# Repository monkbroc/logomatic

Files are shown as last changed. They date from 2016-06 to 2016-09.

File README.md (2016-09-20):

# Logomatic

A gorgeous internet-connected animated logo.

Animated logo (https://www.youtube.com/watch?v=NtJe1kALyLk)

### [Read a writeup about the project](writeup.md) (work in progress)

## Parts

Hardware: PCB, bill of materials

Firmware: software to read animated GIFs and control the LEDs.

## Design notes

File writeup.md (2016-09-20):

# Logomatic

## Make a logo come alive with full color animations

TODO: Better intro

This project combines many maker skills to create a logo sign using laser cut acrylic, a custom printed PCB to drive the LED string and software to play the animations and receive commands through the internet.

# Initial design

TODO: insert napkin drawing

The idea was to build the logo using laser cut acrylic in 3 layers and have LEDs shine through the logo.

The base layer would be opaque white with a hole in the shape of the logo and space for the name. It would also have holes for standoffs, fancy machined aluminium cylinders used to mount the sign to the wall.

The top layer would be frosted acrylic in the shape of the logo, but slightly larger than the hole. The top layer would also have the name in black to make it pop.

The bottom layer would be opaque white with a single strip of Neopixel LEDs cut and glued to it. The LEDs would shine through the top frosted layer.

The layers would be fastened together in some way that would be determined later.

I knew wiring the LEDs would be a pain, but it could be done with enough patience.

Since this was a Particle logo sign I wanted to show off the Particle

The software should be able to play GIF animations from an SD card and also perform so hard-coded animations like breathing a color like the Particle devices do when connected to the internet.

# Drawing template

Lay out the sign that you want to make in Inkscape or Illustrator. Add
the logo and text and the 4 standoffs in the corners. Use little
rectangles the same size as the LEDs to make a nice pattern.

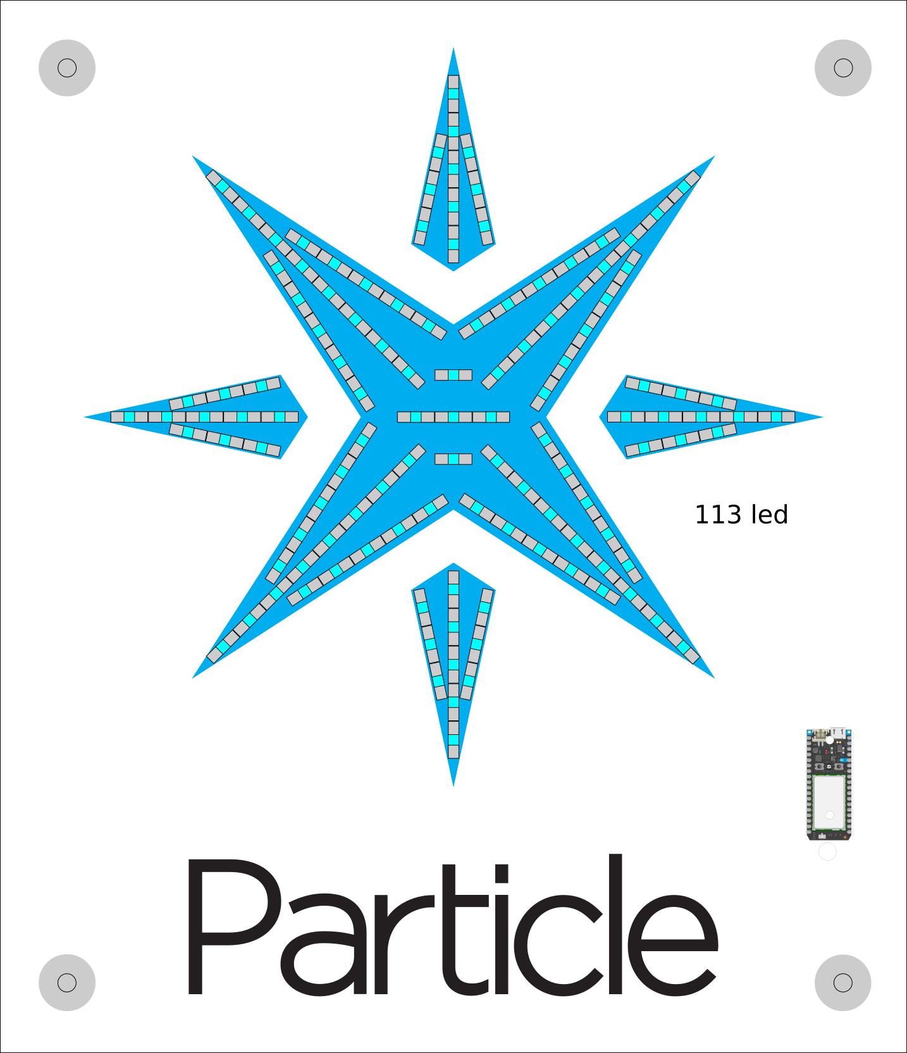
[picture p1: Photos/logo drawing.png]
Drawing template


## Laser cutting

When you are happy with the layout, copy the drawing and turn it into vectors that will be used to drive the laser cutter.

I needed 4 vectors. You can see them in `Mechanical/laser cutter vectors.svg`

First the letters are just cut in a piece of black acrylic.

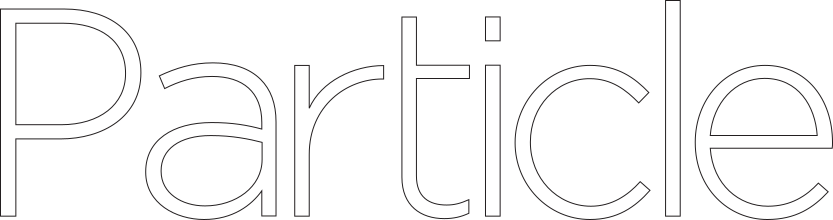
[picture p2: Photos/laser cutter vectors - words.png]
Laser cutter words


Second the logo top layer is just cut in a piece of transparent acrylic. I rotated the points to save material.

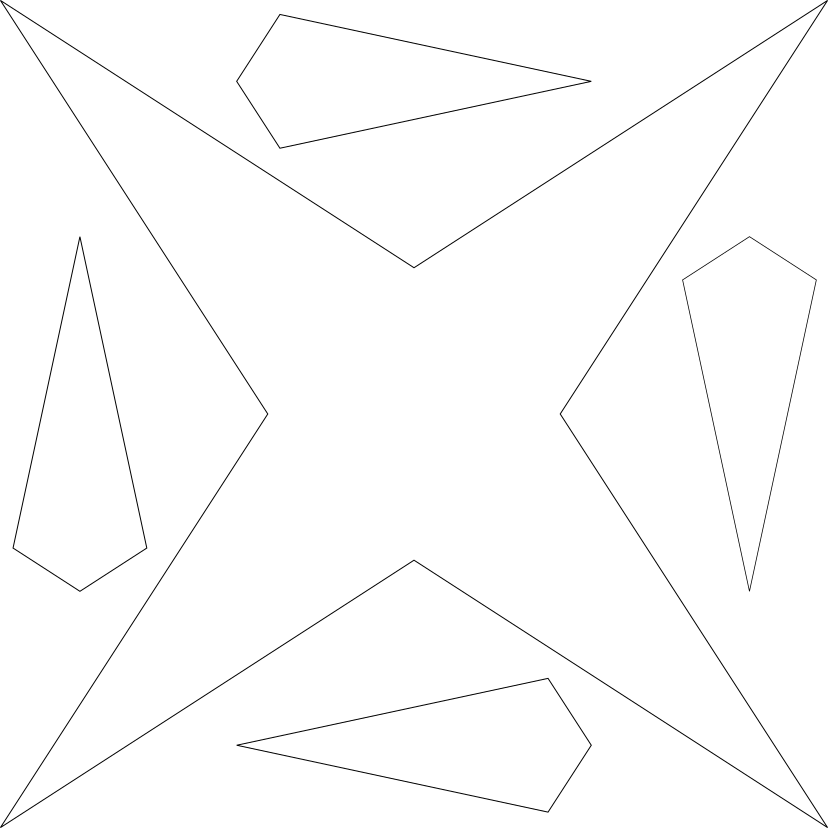
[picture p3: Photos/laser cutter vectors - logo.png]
Laser cutter logo


Third is the base plate cut in a piece of white acrylic. The logo is hole is slighly smaller than the logo top layer. I did this in Inkscape by using Path -> Dynamic offset on the logo and shrinking the logo outline a bit. Using the same technique I made a shrunk down copy of the letters. Instead of cutting those I just etched them to know where to glue the black letters on the base plate.

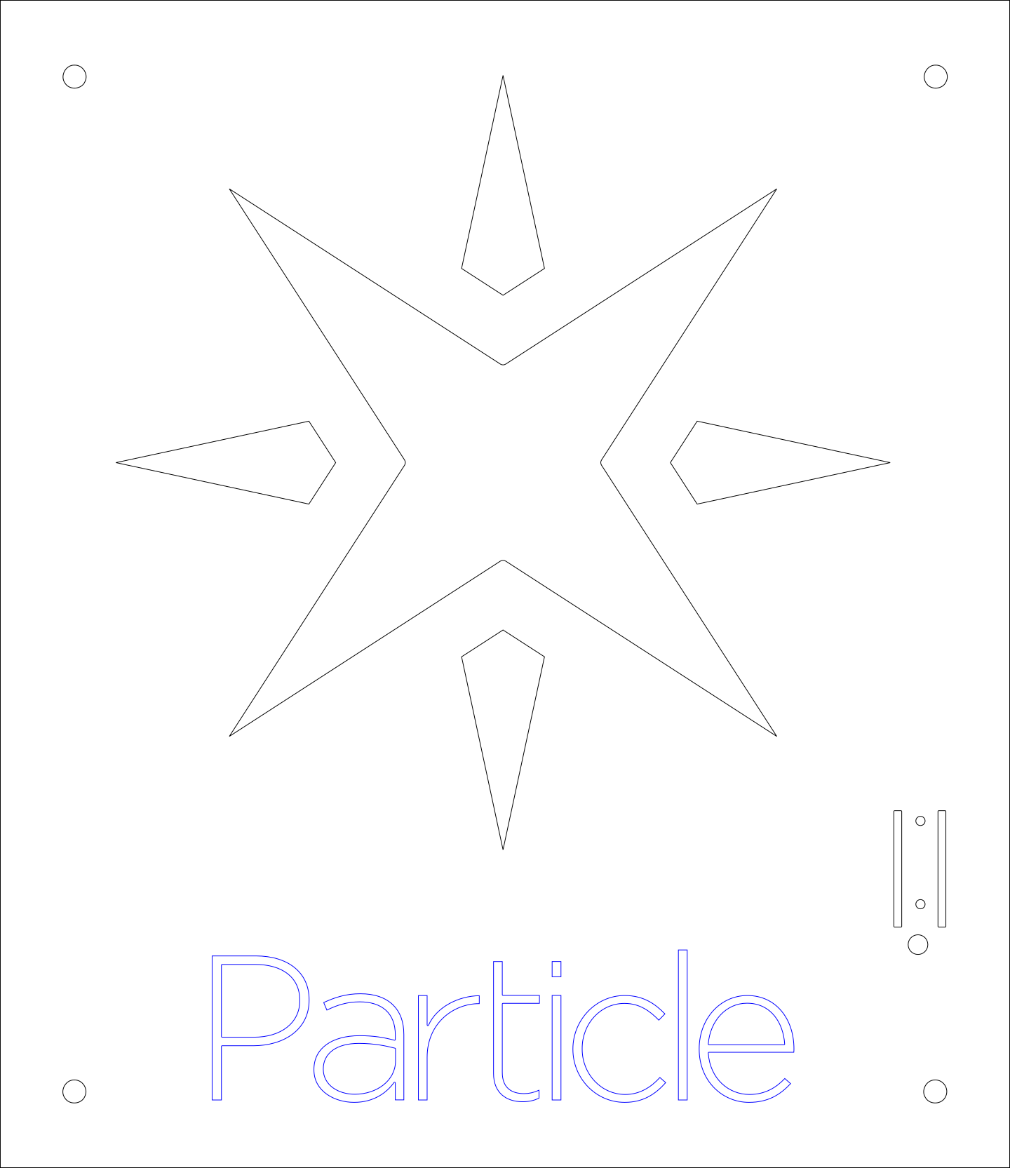
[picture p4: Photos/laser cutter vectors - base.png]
Laser cutter base


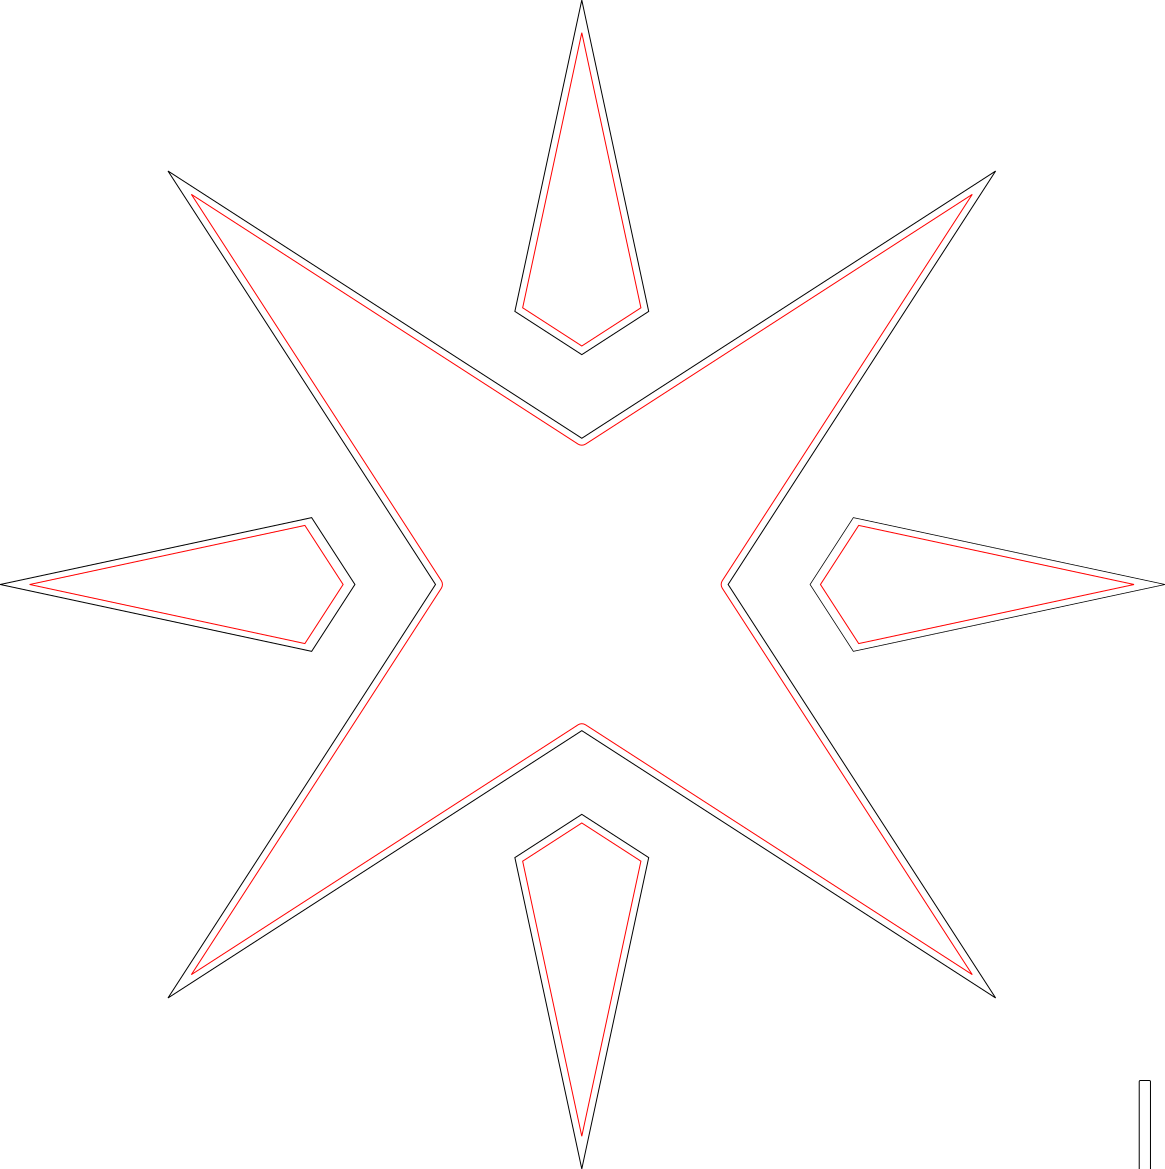
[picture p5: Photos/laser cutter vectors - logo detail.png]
Laser cutter logo details


Finally the back layer holding the LEDs is cut in a piece of white acrylic. The cut outline is made by using Dynamic offset and enlarging the logo. The logo hole and ideal placement of the LEDs are etched to ease assembly later.

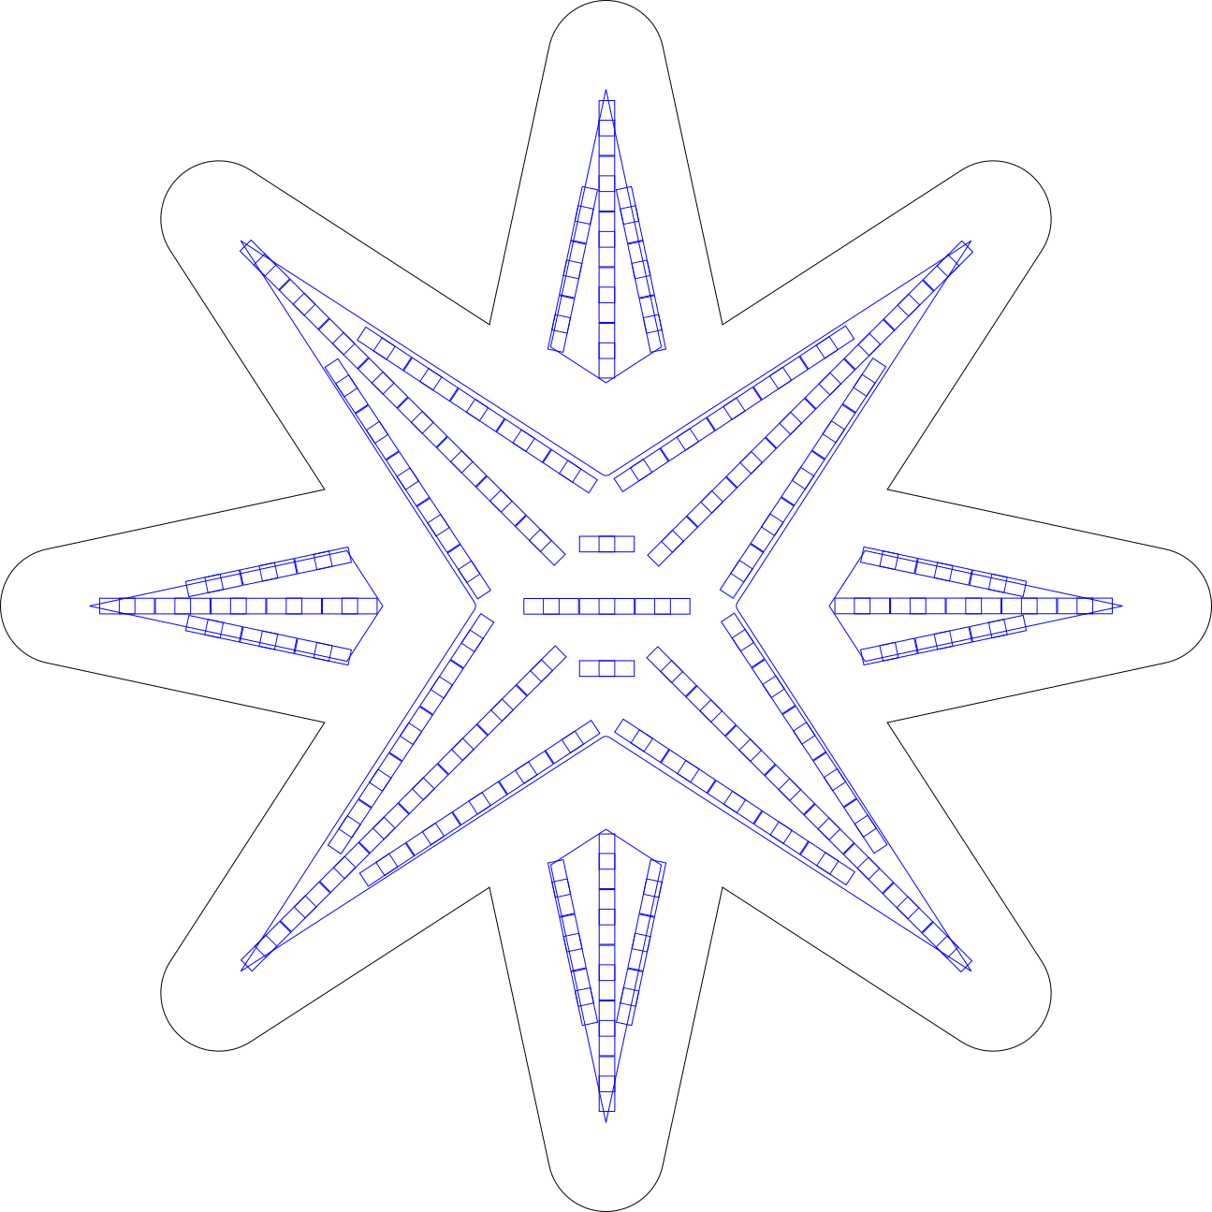
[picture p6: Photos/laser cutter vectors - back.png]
Laser cutter back


Take the files to your local maker space and go cut some plastic!

Here's the result of cutting the base plate.

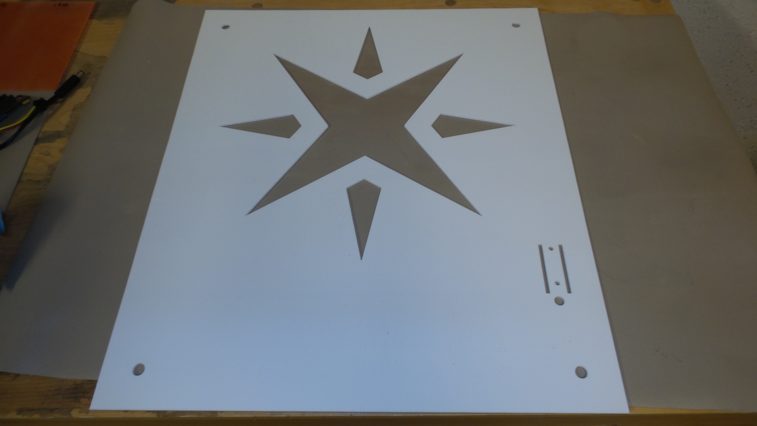
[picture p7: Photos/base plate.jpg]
Base plate


## Assembly

The owner of the plastics shop where I bought my acrylic in Ann Arbor told me that Weld On 4 was the best product for cleanly glueing acryclic. He sold me a small bottle with a seringe that has a goose neck. He mentioned not to use a seringe with a steel needle otherwise I'd need as many needles as drops of glue!

The trick to use Weld On 4 is to place the pieces together, inject a small amount at the seam and wait 3 seconds. That's all it takes to make a strong bond! Weld On 4 melts the acrylic so the 2 pieces become one.

I started by glueing the black letters on the base place using the etched letters on the base plate as a guide.

Before glueing the top logo I sanded the transparent acrylic with an orbital sander and 80 grit sandpaper. I used very little pressure not to create deep swirls on the surface. The result is a nicely frosted piece of acrylic.

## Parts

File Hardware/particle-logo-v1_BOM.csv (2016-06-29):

Qty-1 | Part References | Value | Package | Mfg Part Num | Mfg Name | VID | Vendor Part Num | Description | XREF
1 | C3 | 0.1uF | C0603 | CC0603JRX7R7BB104 | Yageo | DK | 311-1776-1-ND | CAP CER 0.1UF 16V X7R 0603 | REF12
1 | C2 | 1.0UF | 0603-CAP | 0603YD105KAT2A | AVX | DK | 478-1249-1-ND | 1µF ±10% 16V X5R Ceramic Capacitor -55°C ~ 85°C Surface Mount | MLCC 0603 (1608 Metric) | REF52
2 | R1, R3 | 10k | R0603 | ERJ-3EKF1002V | Panasonic | DK | P10.0KHCT-ND | RES SMD 10K OHM 1% 1/10W 0603 | REF54
1 | C4 | 100UF | EIA7343 | TAJD107K020RNJ | AVX | DK | 478-1724-1-ND | CAP TANT 100UF 20V 10% 2917 | REF53
1 | R2 | 220 | R0603 | ERJ-3GEYJ221V | Panasonic | DK | P220GCT-ND | RES SMD 220 OHM 5% 1/10W 0603 | REF55
1 | C1 | 1000uF | CPOL-8MMX20MM-FLAT-MIR | EEU-FR1C102L | Panasonic Electronic Components | DK | P14397-ND | CAP ALUM 1000UF 20% 16V RADIAL | REF51
1 | U2 | APDS-9960 | APDS-9960 | APDS-9960 | Broadcom | AR | apds-9960/broadcom-limited | Light to Digital Ambient Light Sensor 8-Pin | REF57
2 | HEADER1, HEADER2 | BOM-ENTRY | * | PPTC181LFBN-RC | Sullins Connector Solutions | DK | S7016-ND | CONN HEADER FEMALE 18POS.1"" TIN | REF23
1 | R4(DNP), U3 | ELECTRON_WITH_EXTERNAL_HEADERS_NT | ELECTRON_EXTERNAL_NT | ***PART# '*' NOT FOUND*** | * | * | * | * | *
1 | U4 | NL17SZ125SOT553 | SOT-553 | NL17SZ125DTT1G | ON Semiconductor | DK | NL17SZ125DTT1GOSCT-ND | IC BUFFER NONINV 3ST 5TSOP | REF56
2 | JP2, JP1 | PRT-08235 | SCREWTERMINAL-3.5MM-3 | ***PART# '*' NOT FOUND*** | * | * | * | * | *
1 | U1 | USD-SOCKETMOLEX-CORRECT | MICRO-SD-MOLEX-CORRECT | 1040310811 | Molex | DK | WM6357CT-ND | CONN MICRO SD CARD PUSH-PULL R/A | REF24

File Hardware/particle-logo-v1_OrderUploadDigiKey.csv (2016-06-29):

Digi-Key Part No. | Manufacturer Name | Mfr Part No. | Customer Reference | Qty1
* | * | * | JP1/JP2/R4/U3 | 3 | *** PART# '*' NOT FOUND : JP1/JP2/R4/U3
478-1249-1-ND | AVX | 0603YD105KAT2A | C2 | 1
WM6357CT-ND | Molex | 1040310811 | U1 | 1
311-1776-1-ND | Yageo | CC0603JRX7R7BB104 | C3 | 1
P14397-ND | Panasonic Electronic Components | EEU-FR1C102L | C1 | 1
P10.0KHCT-ND | Panasonic | ERJ-3EKF1002V | R1/R3 | 2
P220GCT-ND | Panasonic | ERJ-3GEYJ221V | R2 | 1
NL17SZ125DTT1GOSCT-ND | ON Semiconductor | NL17SZ125DTT1G | U4 | 1
S7016-ND | Sullins Connector Solutions | PPTC181LFBN-RC | HEADER1/HEADER2 | 2
478-1724-1-ND | AVX | TAJD107K020RNJ | C4 | 1

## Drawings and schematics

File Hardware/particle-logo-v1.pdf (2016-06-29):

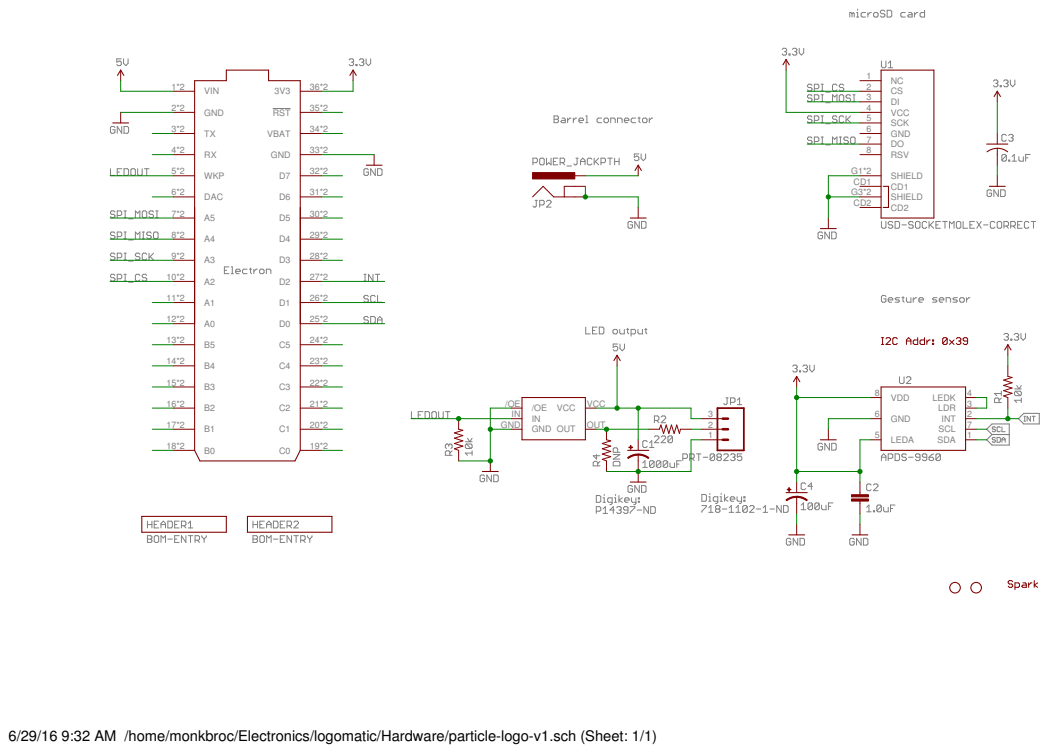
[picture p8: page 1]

6/29/16 9:32 AM /home/monkbroc/Electronics/logomatic/Hardware/particle-logo-v1.sch (Sheet: 1/1)

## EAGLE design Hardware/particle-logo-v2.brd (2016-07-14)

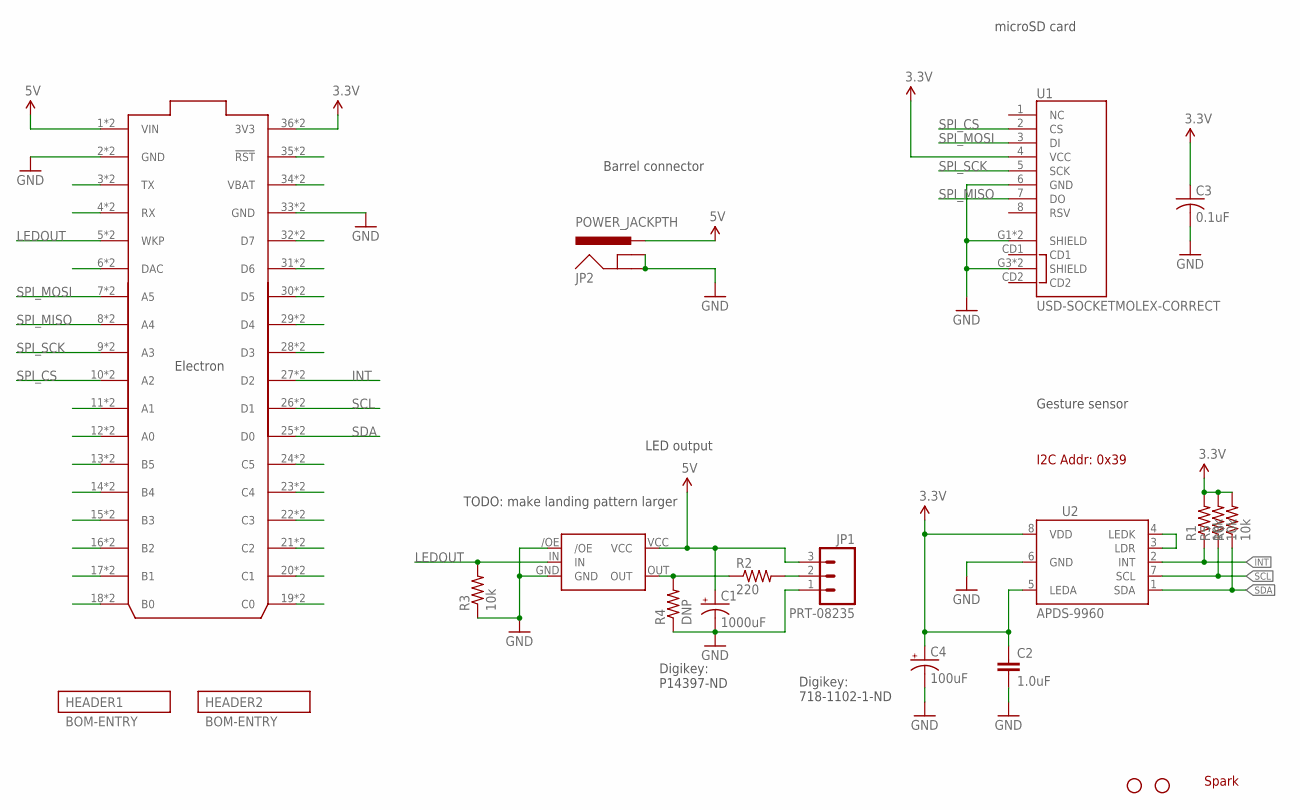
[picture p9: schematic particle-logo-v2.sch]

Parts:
C1: 1000uF; CPOL-8MMX20MM-FLAT-MIR; PARTNO EEU-FR1C102L
C2: 1.0uF; 0603-CAP; PARTNO 0603YD105KAT2A
C3: 0.1uF; C0603; PARTNO CC0603JRX7R7BB104
C4: 100uF; EIA7343; PARTNO TAJD107K020RNJ
JP1: PRT-08235; SCREWTERMINAL-3.5MM-3
JP2: POWER_JACKPTH; POWER_JACK_PTH
R1, R3, R5, R6: 10k; R0603; PARTNO ERJ-3EKF1002V
R2: 220; R0603; PARTNO ERJ-3GEYJ221V
R4: DNP; R0603
STANDOFF1, STANDOFF2: STAND-OFF
U1: USD-SOCKETMOLEX-CORRECT; MICRO-SD-MOLEX-CORRECT; PARTNO 1040310811
U2: APDS-9960; PARTNO APDS-9960
U3: ELECTRON_WITH_EXTERNAL_HEADERS_NT; ELECTRON_EXTERNAL_NT
U4: NL17SZ125SOT553; SOT-553; PARTNO NL17SZ125DTT1G
U$1: SPARK_LOGO2

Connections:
3.3V: C2.1, C3.1, C4.A (+), R1.2, R5.2, R6.2, U1.4 (VCC), U2.5 (LEDA), U2.8 (VDD), U3.36 (3V3), U3.@36 (3V3)
5V: C1.2 (+), JP1.3, JP2.PWR, U3.1 (VIN), U3.@1 (VIN), U4.VCC
GND: C1.1 (-), C2.2, C3.2, C4.C (-), JP1.1, JP2.GND, JP2.GNDBREAK, R3.1, R4.1, U1.6 (GND), U1.G1 (SHIELD), U1.G2 (SHIELD), U1.G3 (SHIELD), U1.G4 (SHIELD), U2.6 (GND), U3.2 (GND), U3.33 (GND), U3.@2 (GND), U3.@33 (GND), U4./OE, U4.GND
INT: R1.1, U2.2 (INT), U3.27 (D2), U3.@27 (D2)
LEDOUT: R3.2, U3.5 (WKP), U3.@5 (WKP), U4.IN
unnamed: R2.1, R4.2, U4.OUT
unnamed: U2.3 (LDR), U2.4 (LEDK)
unnamed: JP1.2, R2.2
unnamed: U3.3 (TX), U3.@3 (TX)
unnamed: U3.4 (RX), U3.@4 (RX)
unnamed: U3.6 (DAC), U3.@6 (DAC)
unnamed: U3.11 (A1), U3.@11 (A1)
unnamed: U3.12 (A0), U3.@12 (A0)
unnamed: U3.13 (B5), U3.@13 (B5)
unnamed: U3.14 (B4), U3.@14 (B4)
unnamed: U3.15 (B3), U3.@15 (B3)
unnamed: U3.16 (B2), U3.@16 (B2)
unnamed: U3.17 (B1), U3.@17 (B1)
unnamed: U3.18 (B0), U3.@18 (B0)
unnamed: U3.19 (C0), U3.@19 (C0)
unnamed: U3.20 (C1), U3.@20 (C1)
unnamed: U3.21 (C2), U3.@21 (C2)
unnamed: U3.22 (C3), U3.@22 (C3)
unnamed: U3.23 (C4), U3.@23 (C4)
unnamed: U3.24 (C5), U3.@24 (C5)
unnamed: U3.28 (D3), U3.@28 (D3)
unnamed: U3.29 (D4), U3.@29 (D4)
unnamed: U3.30 (D5), U3.@30 (D5)
unnamed: U3.31 (D6), U3.@31 (D6)
unnamed: U3.32 (D7), U3.@32 (D7)
unnamed: U3.34 (VBAT), U3.@34 (VBAT)
unnamed: U3.35 (!RST), U3.@35 (!RST)
SCL: R5.1, U2.7 (SCL), U3.26 (D1), U3.@26 (D1)
SDA: R6.1, U2.1 (SDA), U3.25 (D0), U3.@25 (D0)
SPI_CS: U1.2 (CS), U3.10 (A2), U3.@10 (A2)
SPI_MISO: U1.7 (DO), U3.8 (A4), U3.@8 (A4)
SPI_MOSI: U1.3 (DI), U3.7 (A5), U3.@7 (A5)
SPI_SCK: U1.5 (SCK), U3.9 (A3), U3.@9 (A3)

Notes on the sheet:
I2C Addr: 0x39
Gesture sensor
microSD card
Barrel connector
LED output
Digikey: 718-1102-1-ND
Digikey: P14397-ND
TODO: make landing pattern larger

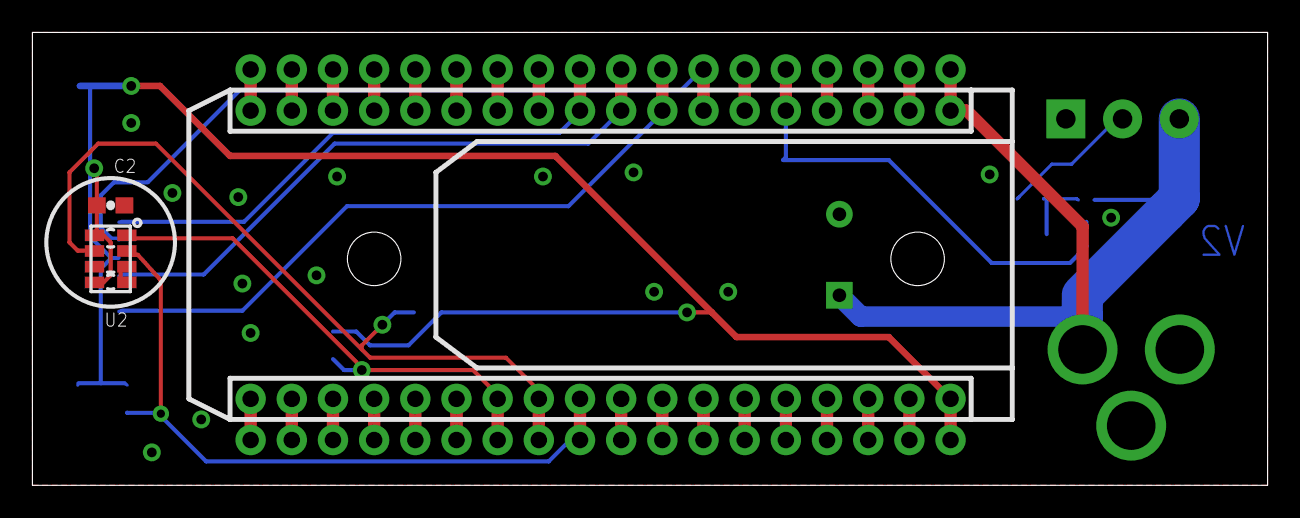
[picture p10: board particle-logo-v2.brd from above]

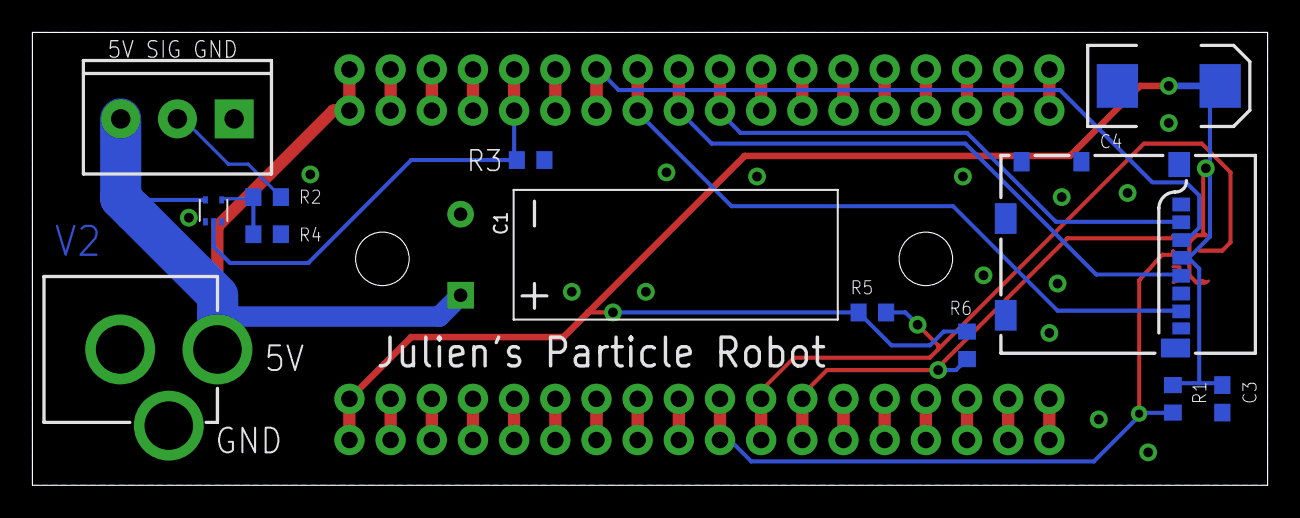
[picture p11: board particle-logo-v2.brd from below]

Board: 2 copper layers, 76.2 x 27.9 mm, 19 parts (16 on the bottom side), 38 nets.

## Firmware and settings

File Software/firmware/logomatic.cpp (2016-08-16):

/* Animated Logo Project
 */

#include "config.h"
#include "math.h"
#include "SdFat.h"
#include "GIFDecoder.h"
#include "SparkFun_APDS9960.h"
#include "gamma.h"
#include "ColorList.h"

#include "GestureSensor.h"
#include "ColorAnimation.h"
#include "DualColorAnimation.h"
#include "BreatheAnimation.h"
#include "BreatheRainbowAnimation.h"
#include "GifAnimation.h"

#include "NeopixelAnimationContext.h"
#include <deque>
using namespace std;

SYSTEM_THREAD(ENABLED);
// Must use a different product ID for Electron vs Photon
#if PLATFORM_ID == 10
PRODUCT_ID(733);
PRODUCT_VERSION(1);
#elif PLATFORM_ID == 6
//PRODUCT_ID(832);
//PRODUCT_VERSION(1);
#endif

void addStartupAnimations();
int startBreatheAnimation(String color);
int startColorAnimation(String color);
int startDualColorAnimation(String color);
int startBreatheRainbowAnimation();
int startGifAnimation(String name);
int displayOff(String);
int publishListOfGif(String);

void processDuringAnimation();
NeopixelAnimationContext context(processDuringAnimation);

/* Queue of animations. The front of the queue is the current animation */
deque<Animation *> animationQueue;

GestureSensor gesture;

SdFat sd;

/** Battery charger **/
PMIC batteryCharger;

/****************************************/


int numFiles, currentFile;


void setupAnimationContext() {
    // Initialize and clear strip
    context.begin();
    context.show();
}

void setupSdCard() {
    // initialize the SD card at full speed
    if (!sd.begin(SD_CHIP_SELECT, SPI_FULL_SPEED)) {
        Serial.println("No SD card");
    }
}

void setupCloud() {
    static bool done = false;
    if (!done && Particle.connected()) {
        Particle.function("breathe", startBreatheAnimation);
        Particle.function("color", startColorAnimation);
        Particle.function("gif", startGifAnimation);
        Particle.function("off", displayOff);
        Particle.function("lsGif", publishListOfGif);
        done = true;
    }
}

// Setup method runs once, when the sketch starts
void setup() {
    // Stop red LED blinking on Electron
    batteryCharger.disableCharging();

	Serial.begin(9600);
    delay(100);
    Serial.println("Logomatic");
    randomSeed(HAL_RNG_GetRandomNumber());

    // FIXME: disable gesture sensor for now
    //gesture.begin();
    setupAnimationContext();
    setupSdCard();

    addStartupAnimations();
}

void abortCurrentAnimations() {
    for (auto it = animationQueue.begin(), end = animationQueue.end(); it != end; ++it) {
        (*it)->abort();
    }
}

void addAnimation(Animation *anim) {
    animationQueue.push_back(anim);
}

void addDefaultAnimation() {
    Animation *anim = new BreatheAnimation{context, ParticleBlue, Animation::FOREVER};
    addAnimation(anim);
}

void shuffle(int *indices, int numFiles) {
    for(int i = numFiles - 1; i > 0; --i) {
        int temp = indices[i];
        int target = random(i + 1);
        indices[i] = indices[target];
        indices[target] = temp;
    }
}

// Play all GIF then breathe rainbows for a while when the device starts
void addStartupAnimations() {
    int numFiles = enumerateGIFFiles(GIF_DIRECTORY, false);

    // randomize gifs
    int *indices = new int[numFiles];
    for(int i = 0; i < numFiles; i++) {
        indices[i] = i;
    }
    shuffle(indices, numFiles);

    for(int i = 0; i < numFiles; i++) {
        char pathname[60];
        getGIFFilenameByIndex(GIF_DIRECTORY, indices[i], pathname);
        addAnimation(new GifAnimation{context, pathname, STARTUP_ANIMATION_TIME});
    }

    addAnimation(new BreatheRainbowAnimation{context, STARTUP_BREATHE_TIME});
}

void nextAnimation() {
    if (!animationQueue.empty()) {
        Animation *previousAnim = animationQueue.front();
        animationQueue.pop_front();
        delete previousAnim;
    }

    if (animationQueue.empty()) {
        addDefaultAnimation();
    }
}

void runCurrentAnimation() {
    if (!animationQueue.empty()) {
        animationQueue.front()->run();
    }
}

void loop() {
    while (true) {
        runCurrentAnimation();
        nextAnimation();
    }
}

// logo breathe sepia
// logo breathe rainbow
int startBreatheAnimation(String colorName) {

    colorName.trim();
    if (colorName.equals("rainbow")) {
        return startBreatheRainbowAnimation();
    }

    Color color = colorFromName(colorName);

    Animation *anim = new BreatheAnimation{context, color, CLOUD_ANIMATION_TIME};
    abortCurrentAnimations();
    addAnimation(anim);

    return 0;
}

// logo color purple
int startColorAnimation(String colorName) {
    if (colorName.indexOf(",") != -1) {
        return startDualColorAnimation(colorName);
    }

    colorName.trim();
    Color color = colorFromName(colorName);

    Animation *anim = new ColorAnimation{context, color, CLOUD_ANIMATION_TIME};
    abortCurrentAnimations();
    addAnimation(anim);

    return 0;
}

// logo color purple, green
int startDualColorAnimation(String colorNames) {
    int commaPos = colorNames.indexOf(",");

    String centerColorName = colorNames.substring(0, commaPos);
    String arrowColorName = colorNames.substring(commaPos + 1);

    centerColorName.trim();
    Color centerColor = colorFromName(centerColorName);

    arrowColorName.trim();
    Color arrowColor = colorFromName(arrowColorName);

    Animation *anim = new DualColorAnimation{context, centerColor, arrowColor, CLOUD_ANIMATION_TIME};
    abortCurrentAnimations();
    addAnimation(anim);

    return 0;
}

int startBreatheRainbowAnimation() {
    Animation *anim = new BreatheRainbowAnimation{context, CLOUD_ANIMATION_TIME};

    abortCurrentAnimations();
    addAnimation(anim);

    return 0;
}

int startGifAnimation(String name) {
    name.trim();
    if (name.length() == 0) {
        return -1;
    }

    name.toLowerCase();
    if (!name.endsWith(".gif")) {
        name += ".gif";
    }
    String pathname = String(GIF_DIRECTORY) + name;

    if (!isValidFile(pathname)) {
        return -2;
    }

    Animation *anim = new GifAnimation{context, pathname, CLOUD_ANIMATION_TIME};
    abortCurrentAnimations();
    addAnimation(anim);

    return 0;
}

int displayOff(String) {
    Color black{0, 0, 0};
    Animation *anim = new ColorAnimation{context, black, Animation::FOREVER};
    abortCurrentAnimations();
    addAnimation(anim);

    return 0;
}


int publishListOfGif(String) {
    String list = "[";
    forEachGIFFile(GIF_DIRECTORY, [&list](const char *filename) {
        if (list.length() > 1) {
            list += ",";
        }
        list += "\"";
        list += filename;
        list += "\"";
    });
    list += "]";
    Particle.publish("gifs", list, PRIVATE);

    return 0;
}

void playNextGif() {
    // currentFile will be incremented after the current animation stops
    currentFile = (currentFile - 2 + numFiles) % numFiles;
}

void playPreviousGif() {
}

bool processGestureSensor() {
    switch (gesture.getGesture()) {
        case DIR_LEFT:
            Serial.println("Left gesture!");
            playNextGif();
            return true;
            break;
        case DIR_RIGHT:
            Serial.println("Right gesture!");
            playPreviousGif();
            return true;
            break;
        case DIR_UP:
            Serial.println("Up gesture!");
            break;
        case DIR_DOWN:
            Serial.println("Down gesture!");
            break;
        case DIR_NEAR:
            Serial.println("Near gesture!");
            break;
        case DIR_FAR:
            Serial.println("Far gesture!");
            break;
    }

    return false;
}

void processDuringAnimation() {
    setupCloud();
    processGestureSensor();

    Particle.process();
}

/*

void shuffle(int *indices, int numFiles) {
    for(int i = numFiles - 1; i > 0; --i) {
        int temp = indices[i];
        int target = random(i + 1);
        indices[i] = indices[target];
        indices[target] = temp;
    }
}

void loop() {
    char pathname[30];

    int *indices = new int[numFiles];
    for(int i = 0; i < numFiles; i++) {
        indices[i] = i;
    }

    // Do forever
    while (true) {
        shuffle(indices, numFiles);

        while(currentFile < numFiles) {
            getGIFFilenameByIndex(GIF_DIRECTORY, indices[currentFile], pathname);

            GifAnimation anim(context, pathname, DISPLAY_TIME_SECONDS * 1000);
            anim.run();

            currentFile++;
        }
        currentFile = 0;
    }
}
*/

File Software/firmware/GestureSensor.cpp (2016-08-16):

#include "GestureSensor.h"
#include "config.h"

const int GestureSensor::processingPeriod = 50; /* ms */

bool GestureSensor::gestureDetected = false;

GestureSensor::GestureSensor()
    : sensor{},
    gesture{DIR_NONE}
{
}

void GestureSensor::begin() {
    pinMode(APDS9960_INT, INPUT);
    // Initialize interrupt service routine
    attachInterrupt(APDS9960_INT, gestureInterrupt, FALLING);

    // Initialize APDS-9960 (configure I2C and initial values)
    if (!sensor.init()) {
        Serial.println("Something went wrong during APDS-9960 init!");
        while(true);
    }

    // Start running the APDS-9960 gesture sensor engine
    if (!sensor.enableGestureSensor(true)) {
        Serial.println("Something went wrong during gesture sensor init!");
        while(true);
    }

    Thread("gesture", [this]() {
        for(;;) {
            processSensor();
            HAL_Delay_Milliseconds(processingPeriod);
        }
    });

    Serial.println("Gesture sensor is now running");
}

int GestureSensor::getGesture() {
    SingleThreadedSection st;
    int ret = gesture;
    gesture = DIR_NONE;
    return ret;
}


void GestureSensor::gestureInterrupt() {
    gestureDetected = true;
}

void GestureSensor::processSensor() {
    if (sensor.isGestureAvailable()) {
        gesture = sensor.readGesture();
    }
}

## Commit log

2016-06-29 Add BOM and schematics PDF
    [particle-logo-v1.brd, particle-logo-v1.sch, particle-logo-v1_BOM.csv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]
2016-07-14 Revise board to fix problems in v1
    - missing i2c pull ups
    - missing 3.3v to gesture sensor
    - missing ground to sd card
    [particle-logo-v2.brd, particle-logo-v2.sch]
2016-07-14 Add gesture sensor to firmware
2016-07-29 Update for longer LED strand
2016-08-02 Wired up the Gif Animation class

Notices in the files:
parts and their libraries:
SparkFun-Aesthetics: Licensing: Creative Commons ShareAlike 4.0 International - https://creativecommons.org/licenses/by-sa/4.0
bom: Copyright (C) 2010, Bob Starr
